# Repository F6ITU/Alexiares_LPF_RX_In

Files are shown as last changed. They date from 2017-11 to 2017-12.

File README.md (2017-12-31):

# Alexiares_LPF_RX_In

THIS PROJECT IS DEPRECATED. DO NOT USE IT WITH ANGELIA/ALEX ARCHITECTURE
(could be used as a simple lpf with notch for any other short waves sdr project

Alex RX 7th order lpf with 88-108 rejection notch

This repository contains the High Pass Filter project of the OpenHPSDR Alexiares frontend

Originaly, this filter is located on the RX, HPF board of Alexiares. 
As the size of this hpf board is limited, it has been decided to 
put this lpf and the TX/RX relay (RXpath and Pure Signal path) on a 
specific board.

The filter is a 7th order lpf with 2 notch rejection frequecies 
centered on the FM broadcast band (88 and 108 MHz). Thus, very strong
FM radio station will not be received in the 4th Nyquist zone of 
the SDR.

A "watertight" rf shielding could be placed around the board or around 
the filter itself. 

The file lpf input.PNG gives a simulation of this filter

Part of this work is protected by the TAPR Open Hardware Licence https://www.tapr.org/ohl.html

Original work by Graham Haddock, KE9H and Phil Harman, VK6APH.

Board's dimensions are undersized to fit the 10x10cm 
size of all board of the Hermes project under Kicad: 

AlexI2C

Alexandrie

Alexiares_Coax_Out 

Alexiares_HPF 

Alexiares_LPF

Mentor

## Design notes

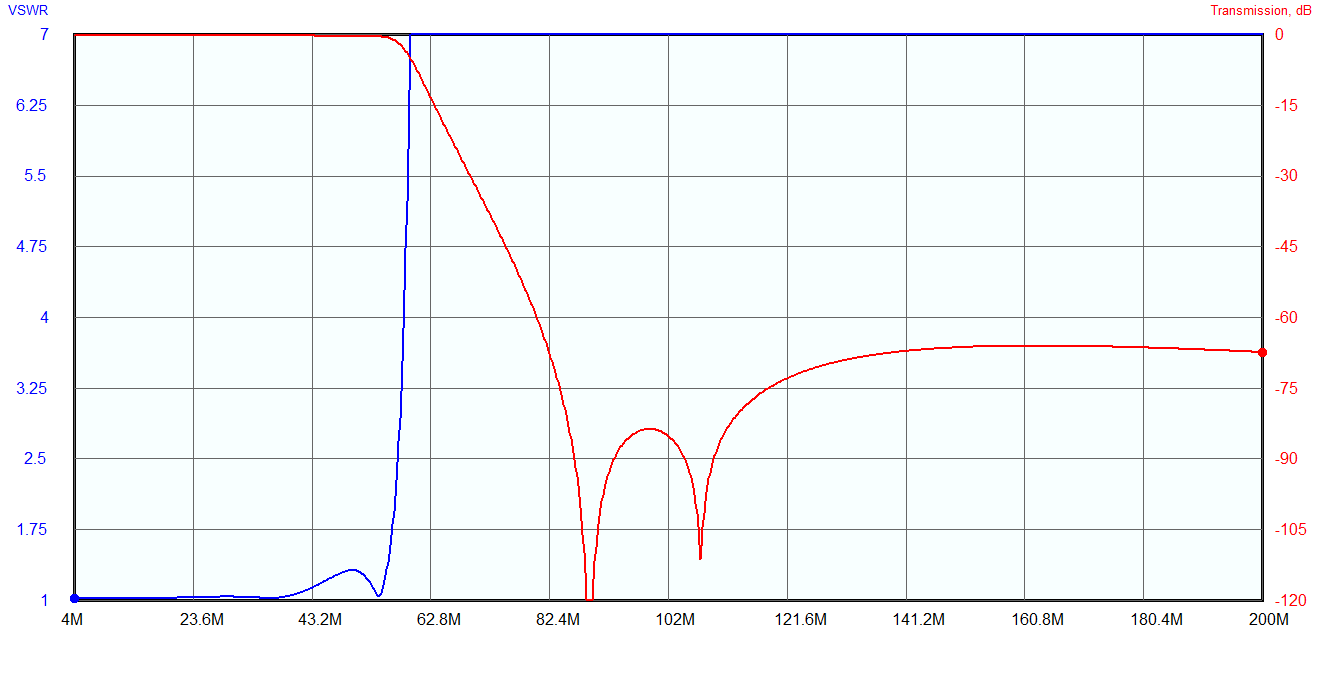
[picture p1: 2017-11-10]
lpf input.PNG

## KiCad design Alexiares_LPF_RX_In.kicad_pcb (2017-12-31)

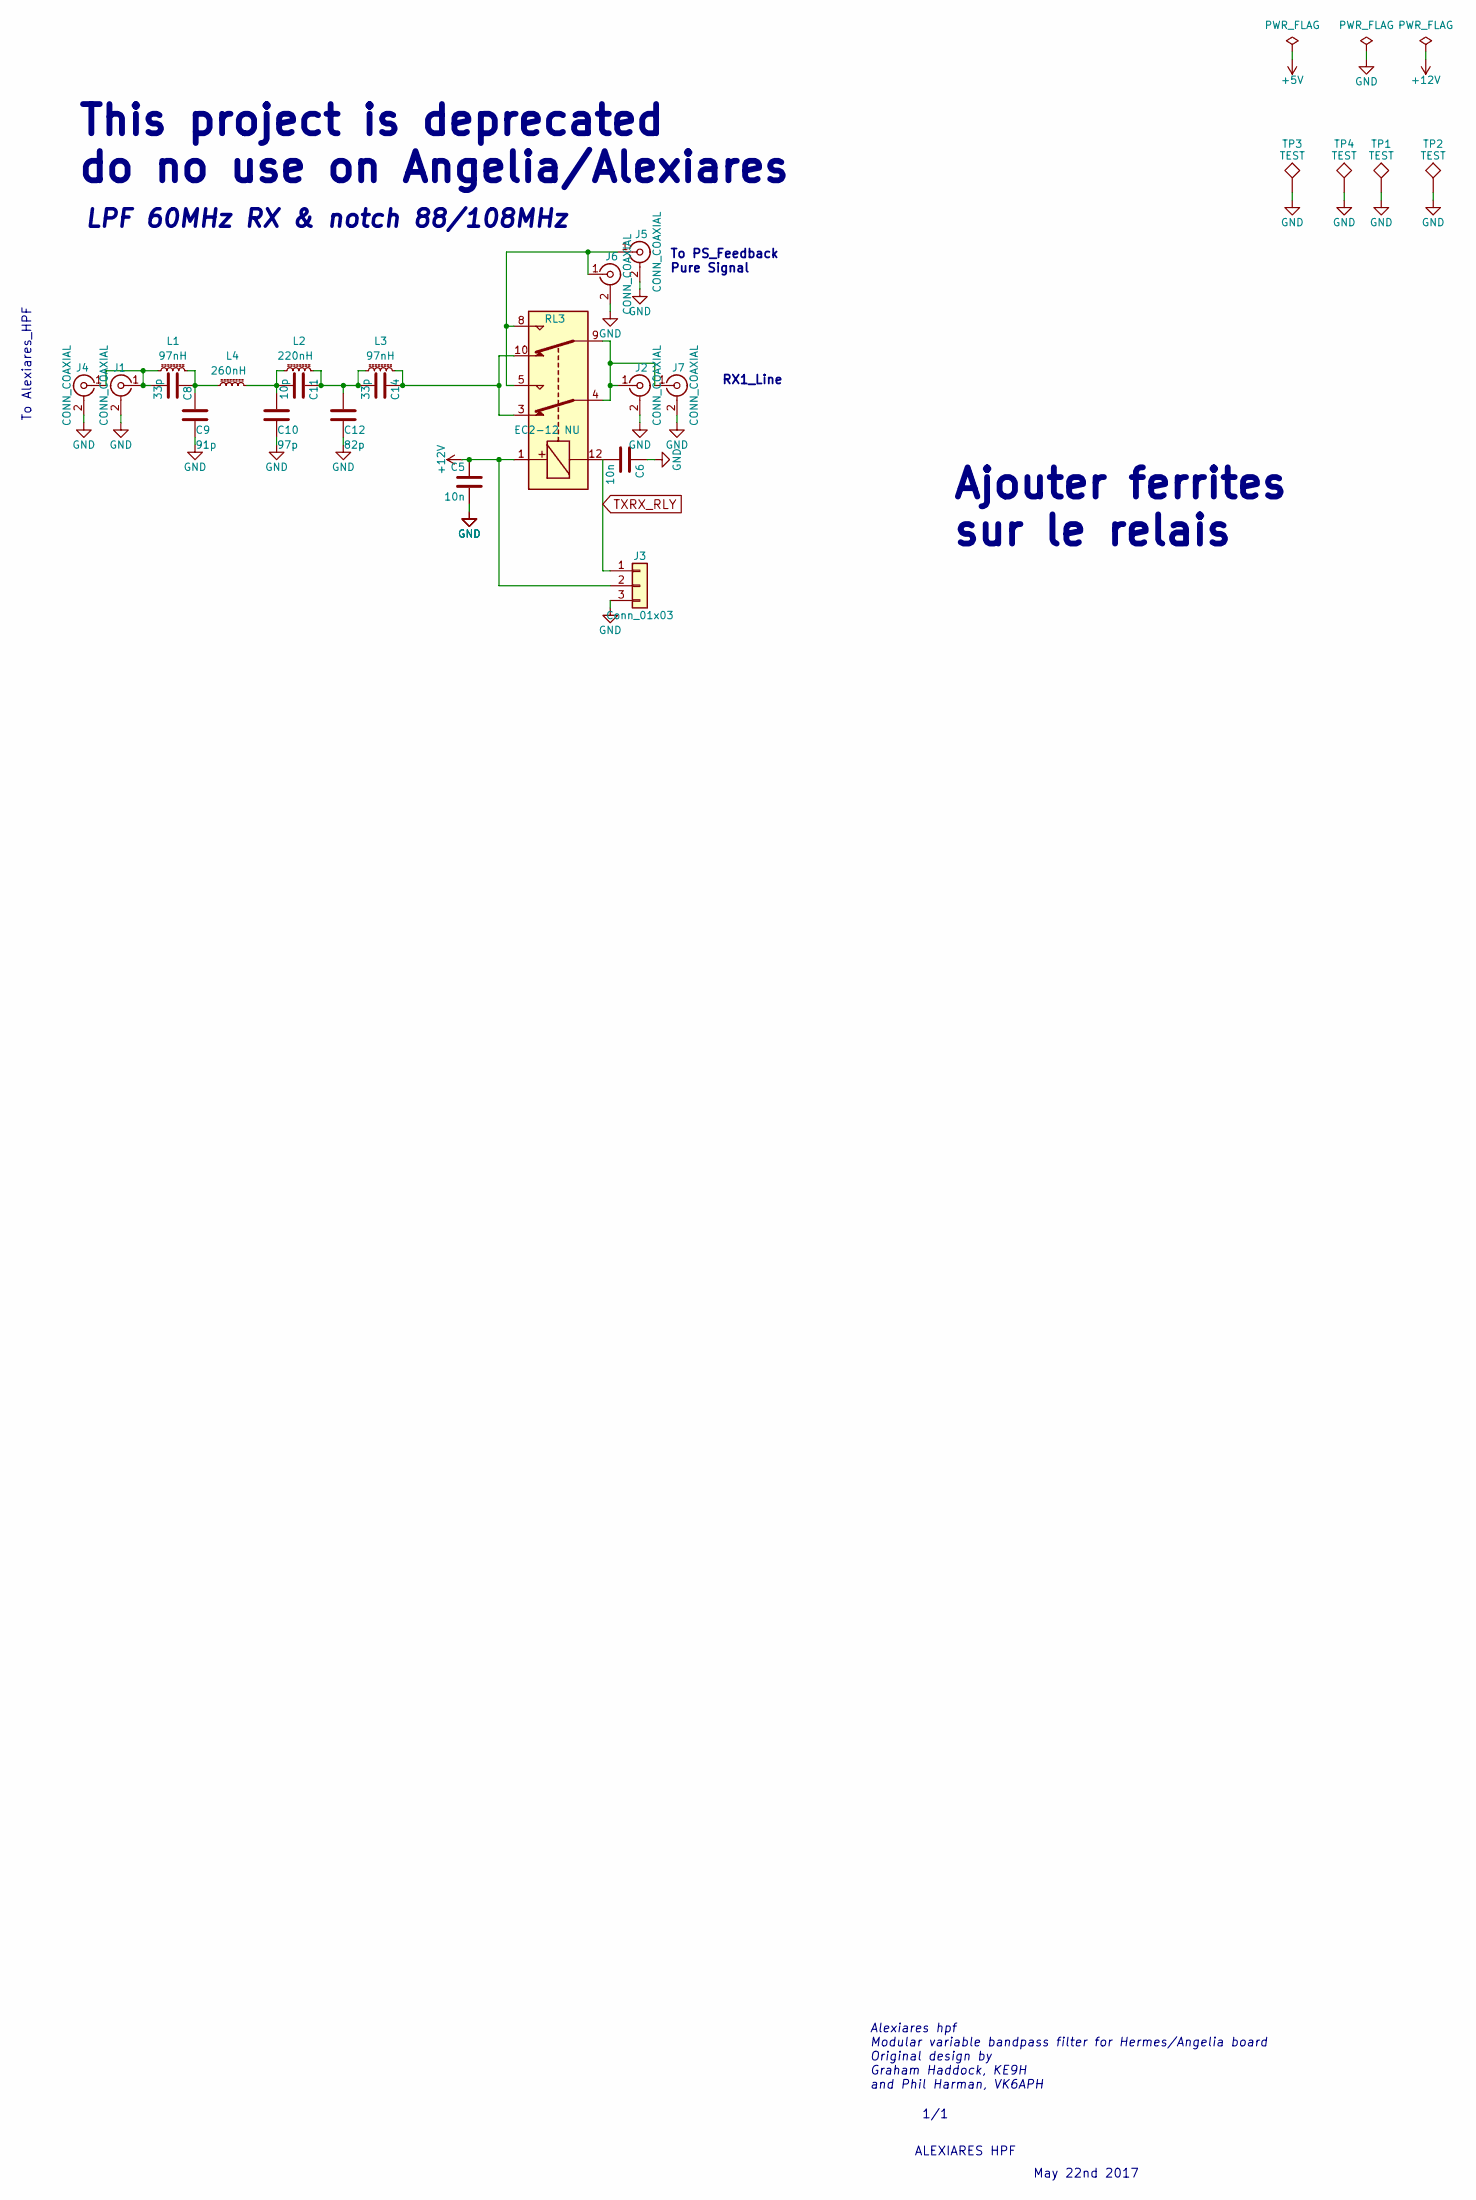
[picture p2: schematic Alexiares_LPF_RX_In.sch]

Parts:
C5, C6: 10n; C_0805_HandSoldering
C8, C14: 33p; ATC_500_HandSoldering
C9: 91p; ATC_500_HandSoldering
C10: 97p; ATC_500_HandSoldering
C11: 10p; ATC_500_HandSoldering
C12: 82p; ATC_500_HandSoldering
J1, J2, J5: CONN_COAXIAL; SMA_THT_Jack_Straight
J3: Conn_01x03; kk100_22-23-2031
J4, J6, J7: CONN_COAXIAL; SMA_EDGE_NRW
L1, L3: 97nH; T50_V_THT
L2: 220nH; T50_V_THT
L4: 260nH; T50_V_THT
RL3: EC2-12 NU; Relay_DPDT_NEC_EC2
TP1, TP2, TP3, TP4: TEST; MountingHole_3.5mm_Pad

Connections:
+12V: C5.1, J3.2, RL3.1
GND: C5.2, C6.1, C9.2, C10.2, C12.2, J1.2 (Ext), J2.2 (Ext), J3.3, J4.2 (Ext), J5.2 (Ext), J6.2 (Ext), J7.2 (Ext), TP1.1, TP2.1, TP3.1, TP4.1
unnamed: C8.1, C9.1, L1.2, L4.1
unnamed: C8.2, J1.1 (In), J4.1 (In), L1.1
unnamed: C10.1, C11.2, L2.1, L4.2
unnamed: C11.1, C12.1, C14.2, L2.2, L3.1
unnamed: C14.1, L3.2, RL3.3, RL3.10
unnamed: J2.1 (In), J7.1 (In), RL3.4, RL3.9
unnamed: J5.1 (In), J6.1 (In), RL3.5, RL3.8
TXRX_RLY: C6.2, J3.1, RL3.12

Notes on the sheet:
Alexiares hpf Modular variable bandpass filter for Hermes/Angelia board Original design by Graham Haddock, KE9H and Phil Harman, VK6APH
1/1
ALEXIARES HPF
May 22nd 2017
RX1_Line
This project is deprecated do no use on Angelia/Alexiares
To PS_Feedback Pure Signal
LPF 60MHz RX & notch 88/108MHz
To Alexiares_HPF
Ajouter ferrites sur le relais

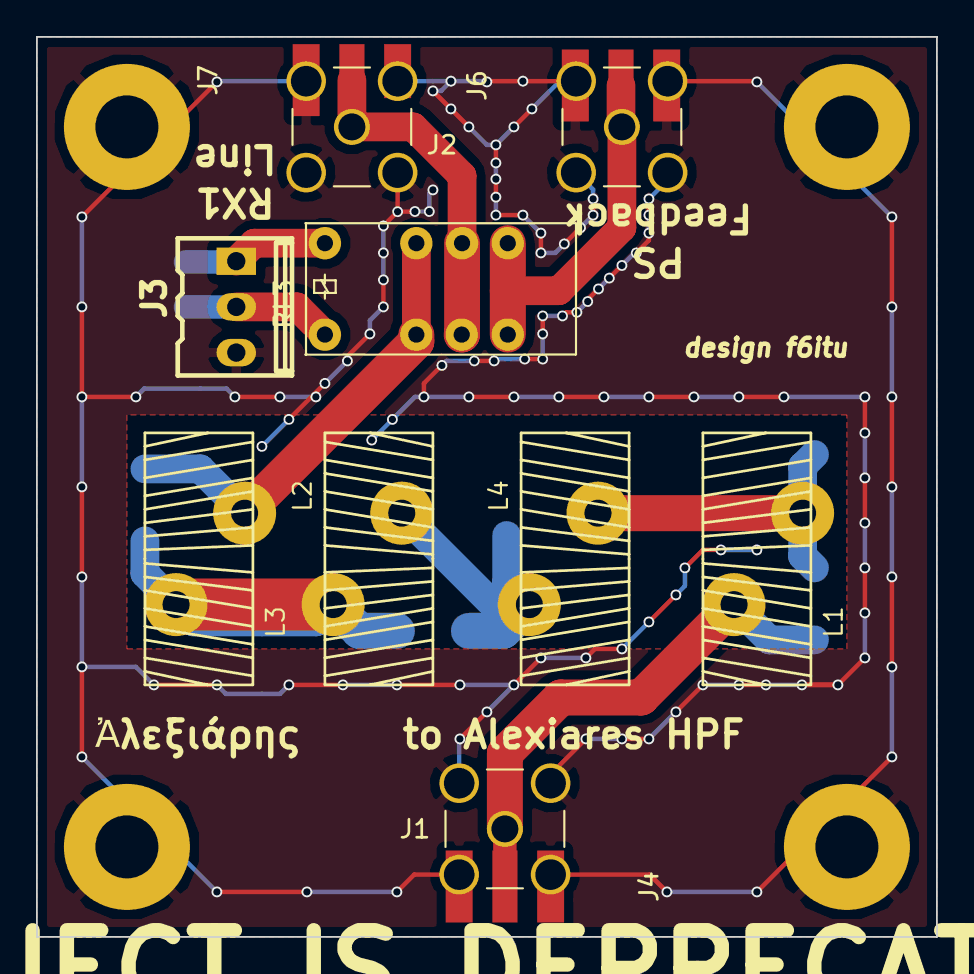
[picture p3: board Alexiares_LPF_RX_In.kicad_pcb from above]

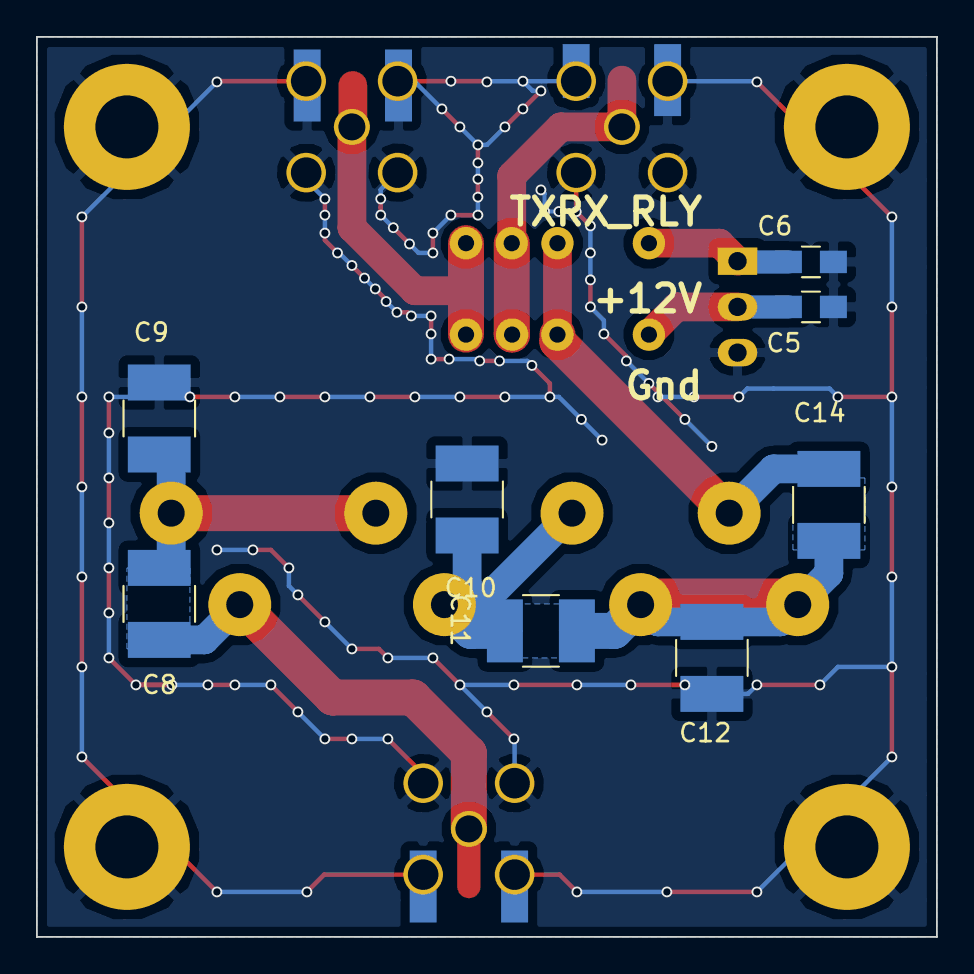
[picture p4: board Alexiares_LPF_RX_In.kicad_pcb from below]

Board: 2 copper layers, 50.0 x 50.0 mm, 24 parts (8 on the bottom side), 10 nets.

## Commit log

2017-11-10 First commit and RTM
    [Alexiares_LPF_RX_In.kicad_pcb, Alexiares_LPF_RX_In.sch]
2017-11-14 Caps changed for ATC footprint
    [Alexiares_LPF_RX_In.kicad_pcb, Alexiares_LPF_RX_In.sch]
2017-11-27 some via added
    [Alexiares_LPF_RX_In.kicad_pcb]
2017-12-31 DEPRECATED PROJECT, DO NOT USE WITH ALEX
    [Alexiares_LPF_RX_In.kicad_pcb, Alexiares_LPF_RX_In.sch]
